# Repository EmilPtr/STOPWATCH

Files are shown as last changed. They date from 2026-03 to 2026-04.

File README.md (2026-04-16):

# Stopwatch
This is a simple stopwatch PCB that was intended for me to get into the complex world of PCB design and microcontrollers on PCBs. It functions like a regular stopwatch, you cna start the timer, stop it, and reset it, and it has an accuracy to tens of miliseconds.

## Schematic
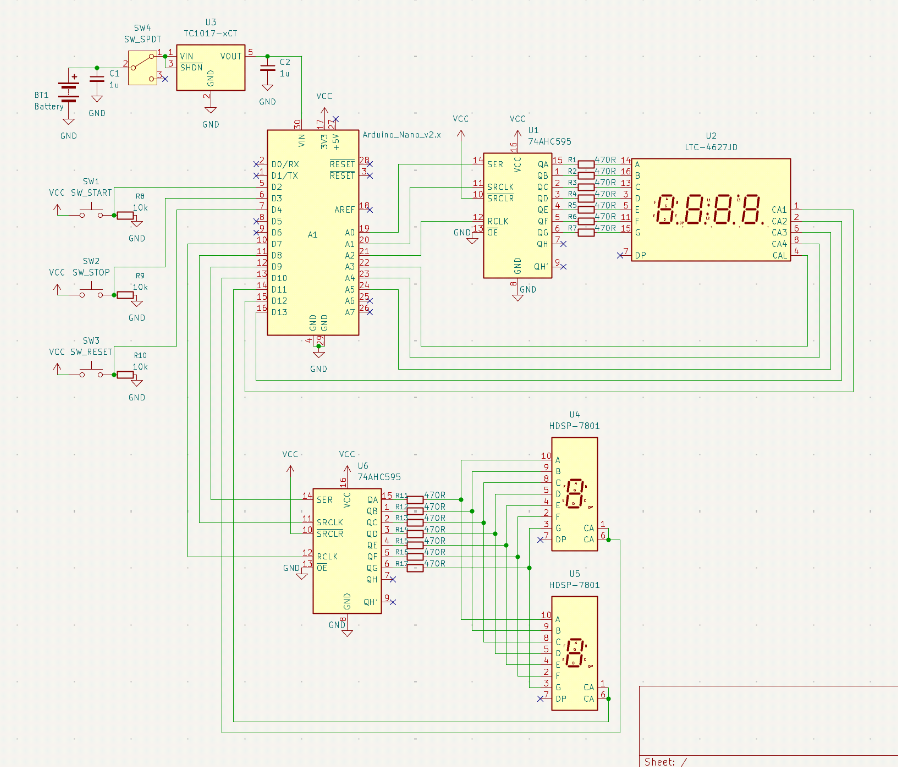
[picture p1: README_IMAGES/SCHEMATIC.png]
schematic

the schematic looks like this, it consists of several HC595 8-bit shift registers to multiplex the MCU's pins for minimal pin usage on displays, some buttons for control, and a 3.3V regulator to regulate a 3xAA battery's voltage to power the MCU in a stable fashion.

## PCB 
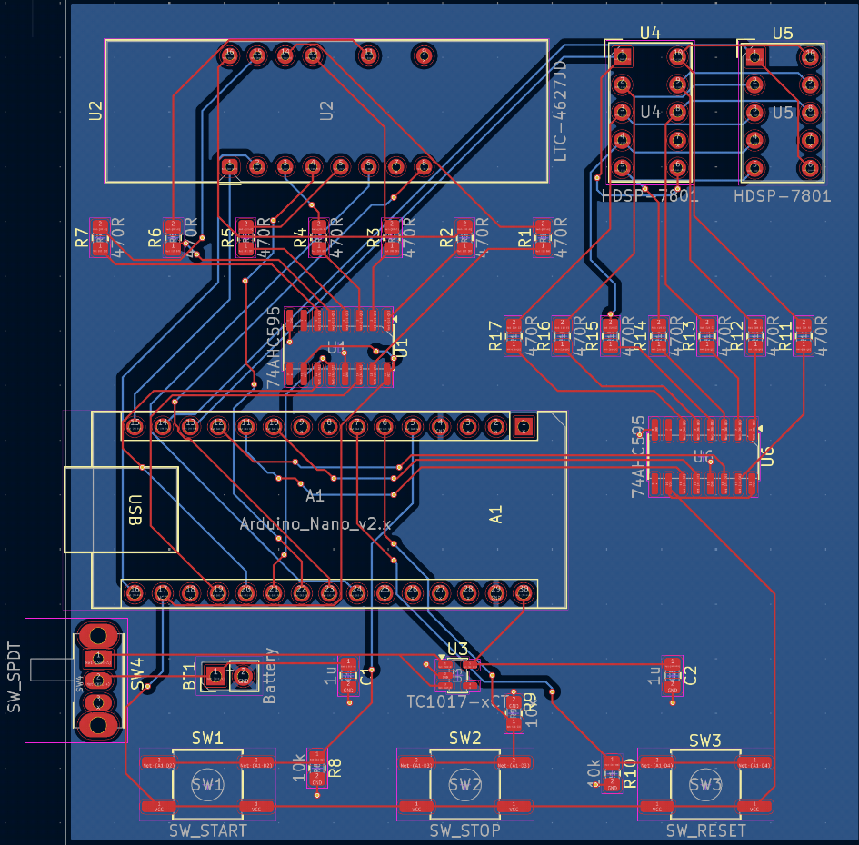
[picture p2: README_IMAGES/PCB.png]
pcb

The PCB uses only 2 layers to be as cost effective as possible and stays within 100mm x 100mm to capitalize on JLCPCB's lowest cost threshold. It was designed in a way where traces of similar functionality are grouped together, but not close enough to be affected by other traces by Faraday's Law.

## Physical Build
YAYYY ITS DONE!!! :D
https://github.com/user-attachments/assets/ebe392f2-ca30-4a46-b4f1-2a95856c1f90

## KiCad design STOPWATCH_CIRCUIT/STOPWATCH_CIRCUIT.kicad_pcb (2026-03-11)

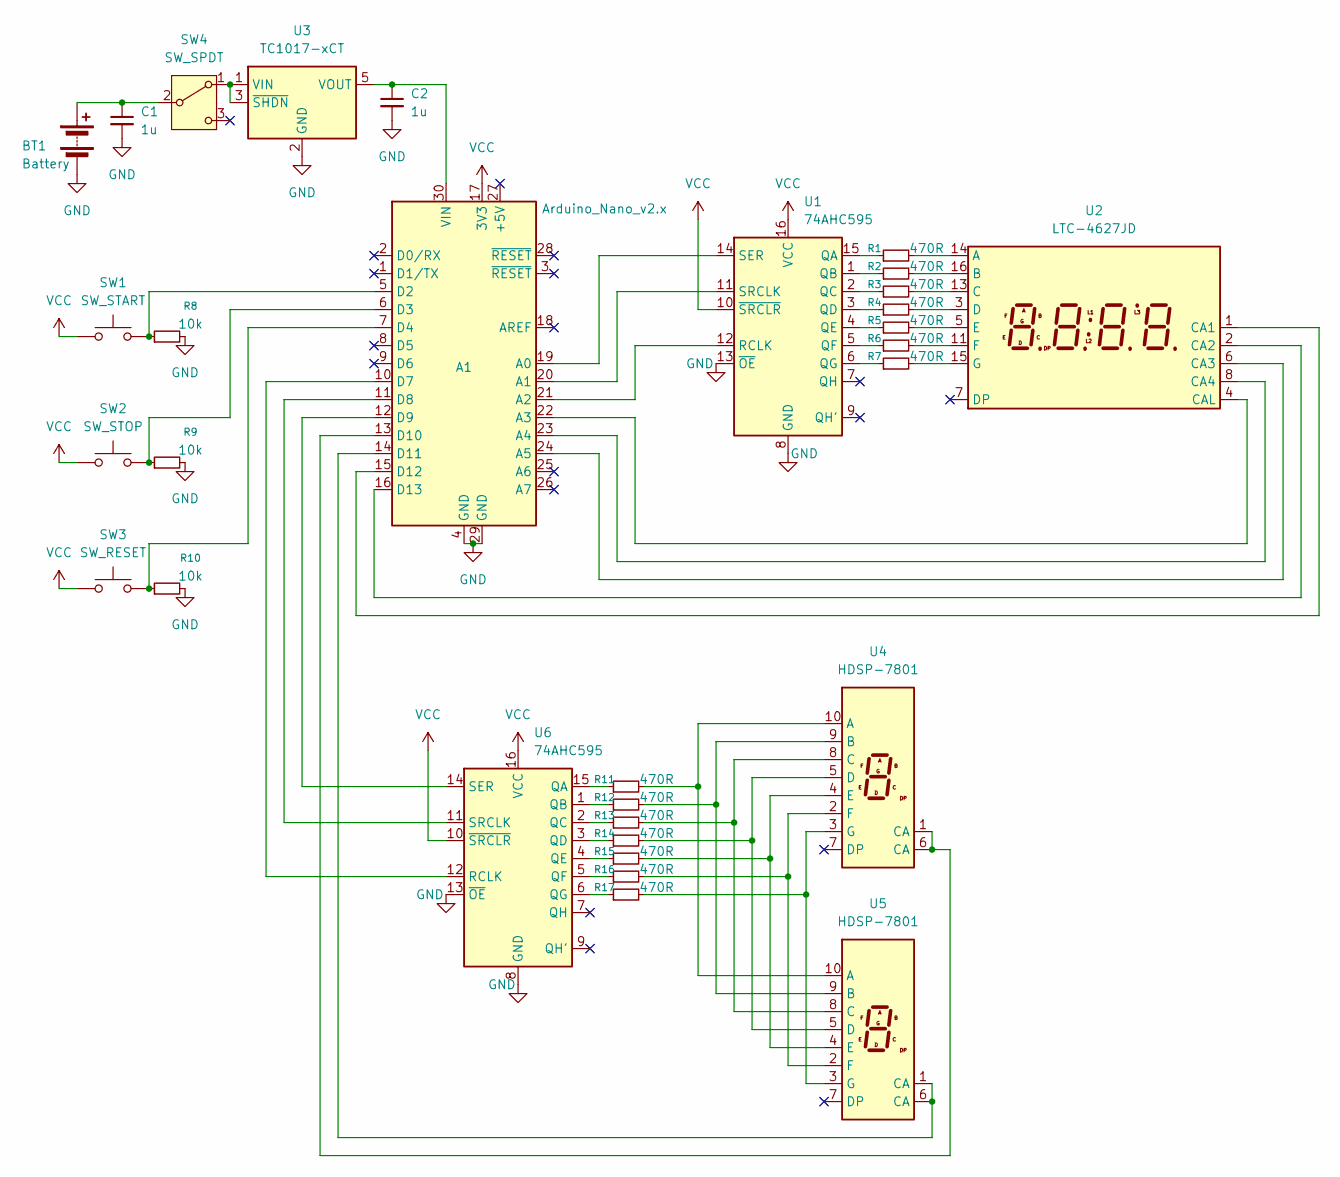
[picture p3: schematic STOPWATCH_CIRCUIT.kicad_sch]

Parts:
A1: Arduino_Nano_v2.x; Arduino_Nano
BT1: Battery; PinHeader_1x02_P2.54mm_Vertical
C1, C2: 1u; C_0805_2012Metric_Pad1.18x1.45mm_HandSolder
R1, R2, R3, R4, R5, R6, R7, R11, R12, R13, R14, R15, R16, R17: 470R; R_0805_2012Metric_Pad1.20x1.40mm_HandSolder
R8, R9, R10: 10k; R_0805_2012Metric_Pad1.20x1.40mm_HandSolder
SW1: SW_START; SW_Push_1P1T_NO_CK_KSC9xxG
SW2: SW_STOP; SW_Push_1P1T_NO_CK_KSC9xxG
SW3: SW_RESET; SW_Push_1P1T_NO_CK_KSC9xxG
SW4: SW_SPDT; SW_Slide_SPDT_Angled_CK_OS102011MA1Q
U1, U6: 74AHC595; SOIC-16_3.9x9.9mm_P1.27mm
U2: LTC-4627JD; LTC-4627Jx
U3: TC1017-xCT; SOT-23-5
U4, U5: HDSP-7801

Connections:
GND: A1.4 (GND), A1.29 (GND), BT1.2 (-), C1.2, C2.2, R8.2, R9.2, R10.2, U1.8 (GND), U1.13 (~OE), U3.2 (GND), U6.8 (GND), U6.13 (~OE)
unnamed: A1.19 (A0), U1.14 (SER)
unnamed: A1.20 (A1), U1.11 (SRCLK)
unnamed: A1.21 (A2), U1.12 (RCLK)
unnamed: A1.22 (A3), U2.4 (CAL)
unnamed: A1.23 (A4), U2.8 (CA4)
unnamed: A1.24 (A5), U2.6 (CA3)
unnamed: A1.5 (D2), R8.1, SW1.2
unnamed: A1.6 (D3), R9.1, SW2.2
unnamed: A1.7 (D4), R10.1, SW3.2
unnamed: A1.10 (D7), U6.12 (RCLK)
unnamed: A1.11 (D8), U6.11 (SRCLK)
unnamed: A1.12 (D9), U6.14 (SER)
unnamed: A1.13 (D10), U4.1 (CA), U4.6 (CA)
unnamed: A1.14 (D11), U5.1 (CA), U5.6 (CA)
unnamed: A1.15 (D12), U2.1 (CA1)
unnamed: A1.16 (D13), U2.2 (CA2)
unnamed: A1.30 (VIN), C2.1, U3.5 (VOUT)
unnamed: BT1.1 (+), C1.1, SW4.2 (B)
unnamed: SW4.1 (A), U3.1 (VIN), U3.3 (~SHDN)
unnamed: R1.1, U1.15 (QA)
unnamed: R2.1, U1.1 (QB)
unnamed: R3.1, U1.2 (QC)
unnamed: R4.1, U1.3 (QD)
unnamed: R5.1, U1.4 (QE)
unnamed: R6.1, U1.5 (QF)
unnamed: R7.1, U1.6 (QG)
unnamed: R1.2, U2.14 (A)
unnamed: R2.2, U2.16 (B)
unnamed: R3.2, U2.13 (C)
unnamed: R4.2, U2.3 (D)
unnamed: R5.2, U2.5 (E)
unnamed: R6.2, U2.11 (F)
unnamed: R7.2, U2.15 (G)
unnamed: R11.2, U4.10 (A), U5.10 (A)
unnamed: R12.2, U4.9 (B), U5.9 (B)
unnamed: R13.2, U4.8 (C), U5.8 (C)
unnamed: R14.2, U4.5 (D), U5.5 (D)
unnamed: R15.2, U4.4 (E), U5.4 (E)
unnamed: R16.2, U4.2 (F), U5.2 (F)
unnamed: R17.2, U4.3 (G), U5.3 (G)
unnamed: R11.1, U6.15 (QA)
unnamed: R12.1, U6.1 (QB)
unnamed: R13.1, U6.2 (QC)
unnamed: R14.1, U6.3 (QD)
unnamed: R15.1, U6.4 (QE)
unnamed: R16.1, U6.5 (QF)
unnamed: R17.1, U6.6 (QG)
VCC: A1.17 (3V3), SW1.1, SW2.1, SW3.1, U1.10 (~SRCLR), U1.16 (VCC), U6.10 (~SRCLR), U6.16 (VCC)

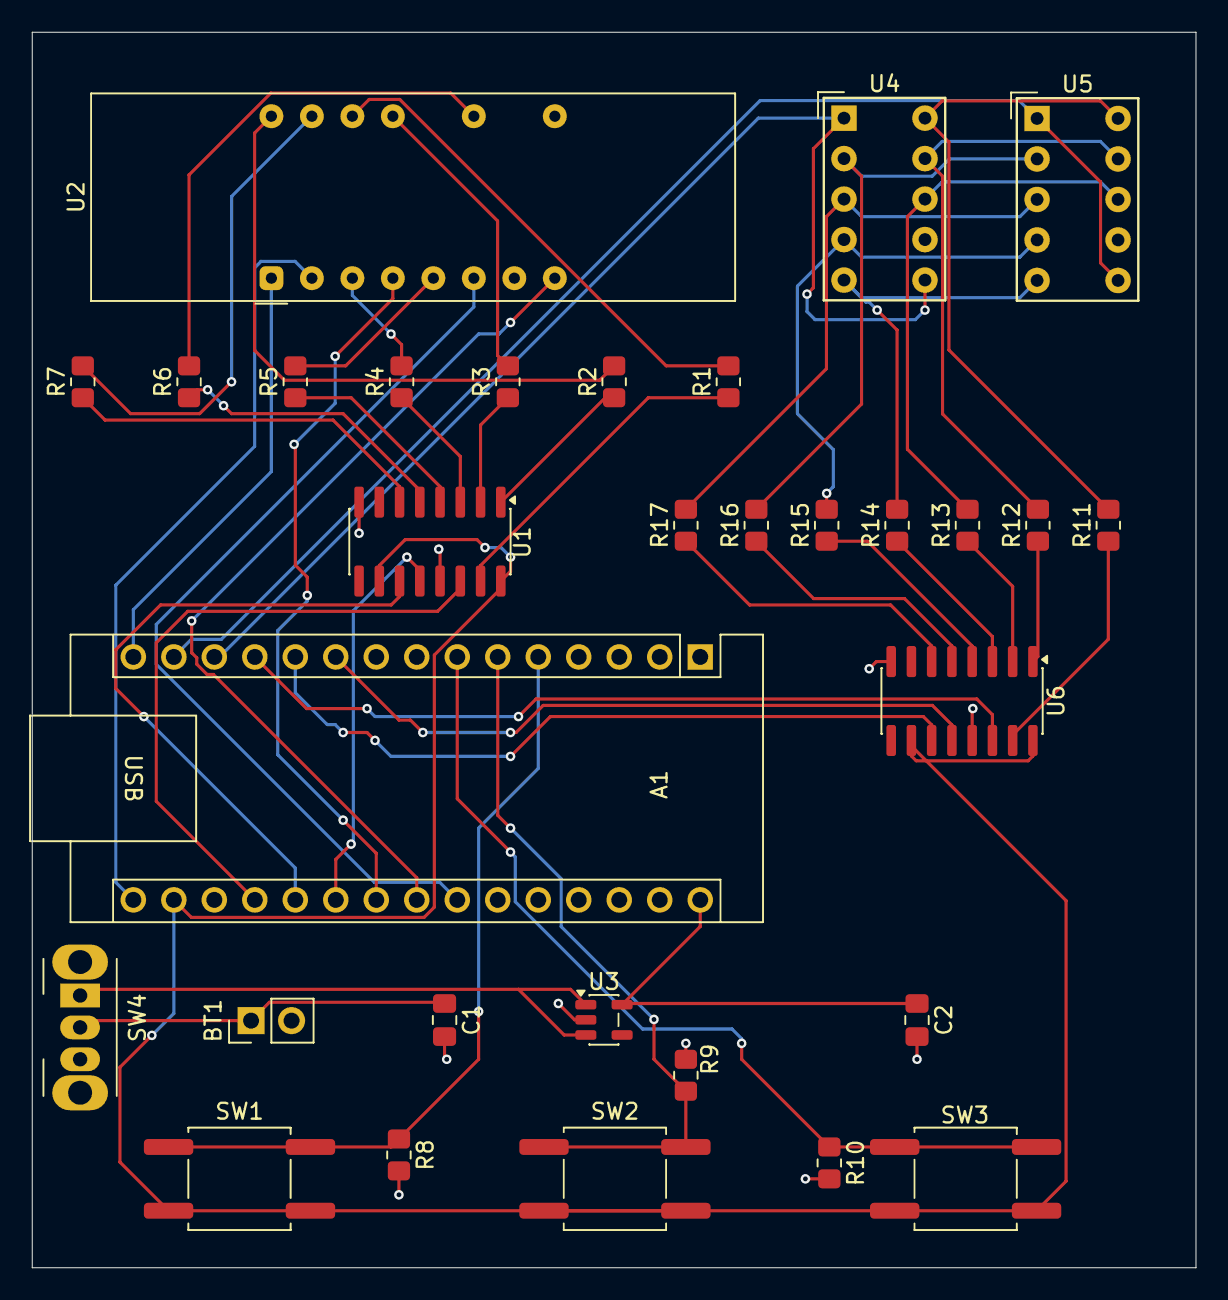
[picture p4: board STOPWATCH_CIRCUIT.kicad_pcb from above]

Board: 2 copper layers, 73.0 x 77.5 mm, 31 parts (0 on the bottom side), 49 nets.

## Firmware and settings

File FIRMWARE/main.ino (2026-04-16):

#define DP_4 A0
#define CP_4 A1
#define LP_4 A2

#define DP_2 9
#define CP_2 8
#define LP_2 7

#define DIG_SEC_1 A5
#define DIG_SEC_2 A4

#define DIG_MSEC_1 10
#define DIG_MSEC_2 11

#define DIG_MIN_1 12
#define DIG_MIN_2 13

#define START 2
#define STOP 3
#define RESET 4

unsigned long offset = 0;
unsigned long prevMillis = 0;

bool counting = true;

const uint8_t digitMap[10] = {
  0b11000000,  // 0
  0b11111001,  // 1
  0b10100100,  // 2
  0b10110000,  // 3
  0b10011001,  // 4
  0b10010010,  // 5
  0b10000010,  // 6
  0b11111000,  // 7
  0b10000000,  // 8
  0b10010000   // 9
};

void writeHC595(uint8_t data, int dataPin, int clockPin, int latchPin) {
  digitalWrite(latchPin, LOW);
  shiftOut(dataPin, clockPin, MSBFIRST, data);
  digitalWrite(latchPin, HIGH);
}

void setup() {
  pinMode(2, INPUT);
  pinMode(3, INPUT);
  pinMode(4, INPUT);
  pinMode(7, OUTPUT);
  pinMode(8, OUTPUT);
  pinMode(9, OUTPUT);
  pinMode(10, OUTPUT);
  pinMode(11, OUTPUT);
  pinMode(12, OUTPUT);
  pinMode(13, OUTPUT);
  pinMode(A0, OUTPUT);
  pinMode(A1, OUTPUT);
  pinMode(A2, OUTPUT);
  pinMode(A4, OUTPUT);
  pinMode(A5, OUTPUT);
  
}

void loop() {
  unsigned long millisec = millis()-offset;
  int mins = millisec / 60000;
  int secs = (millisec % 60000) / 1000;
  int msec = (millisec % 1000) / 10; // FIX: 0–99 instead of 0–999

  char msecstr[3]; 
  char secsstr[3]; 
  char minsstr[3];

  sprintf(msecstr, "%02d", msec);
  sprintf(secsstr, "%02d", secs);
  sprintf(minsstr, "%02d", mins);

  // ---- MSEC 1 ----
  writeHC595(digitMap[msecstr[0]-'0'], DP_2, CP_2, LP_2);
  digitalWrite(DIG_MSEC_1, HIGH);
  delay(2);
  digitalWrite(DIG_MSEC_1, LOW);

  // ---- MSEC 2 ----
  writeHC595(digitMap[msecstr[1]-'0'], DP_2, CP_2, LP_2);
  digitalWrite(DIG_MSEC_2, HIGH);
  delay(2);
  digitalWrite(DIG_MSEC_2, LOW);

  // ---- SEC 1 ----
  writeHC595(digitMap[secsstr[0]-'0'], DP_4, CP_4, LP_4);
  digitalWrite(DIG_SEC_1, HIGH);
  delay(2);
  digitalWrite(DIG_SEC_1, LOW);

  // ---- SEC 2 ----
  writeHC595(digitMap[secsstr[1]-'0'], DP_4, CP_4, LP_4);
  digitalWrite(DIG_SEC_2, HIGH);
  delay(2);
  digitalWrite(DIG_SEC_2, LOW);

  // ---- MIN 1 ----
  writeHC595(digitMap[minsstr[0]-'0'], DP_4, CP_4, LP_4);
  digitalWrite(DIG_MIN_1, HIGH);
  delay(2);
  digitalWrite(DIG_MIN_1, LOW);

  // ---- MIN 2 ----
  writeHC595(digitMap[minsstr[1]-'0'], DP_4, CP_4, LP_4);
  digitalWrite(DIG_MIN_2, HIGH);
  delay(2);
  digitalWrite(DIG_MIN_2, LOW);

  if (digitalRead(STOP) && counting) {
    counting = false;
  }

  if (digitalRead(START) && !counting) {
    counting = true;
  }

  if (!counting) {
    offset += millis()-prevMillis;
  }
  
  if (digitalRead(RESET)) {
    offset = millis();
  }

  prevMillis = millis();
}

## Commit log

2026-03-09 Finished design schematic and PCB
    [STOPWATCH_CIRCUIT.kicad_pcb, STOPWATCH_CIRCUIT.kicad_sch]
2026-03-11 Finished adding the 2 extra digits for miliseconds and redid the whole board
    [STOPWATCH_CIRCUIT.kicad_pcb, STOPWATCH_CIRCUIT.kicad_sch]
2026-03-11 Finalized design
    [STOPWATCH_CIRCUIT.kicad_pcb]
2026-04-16 Add main Arduino firmware for timer functionality
